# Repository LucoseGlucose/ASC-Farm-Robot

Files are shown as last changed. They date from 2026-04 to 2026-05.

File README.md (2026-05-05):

# ASC-Farm-Robot

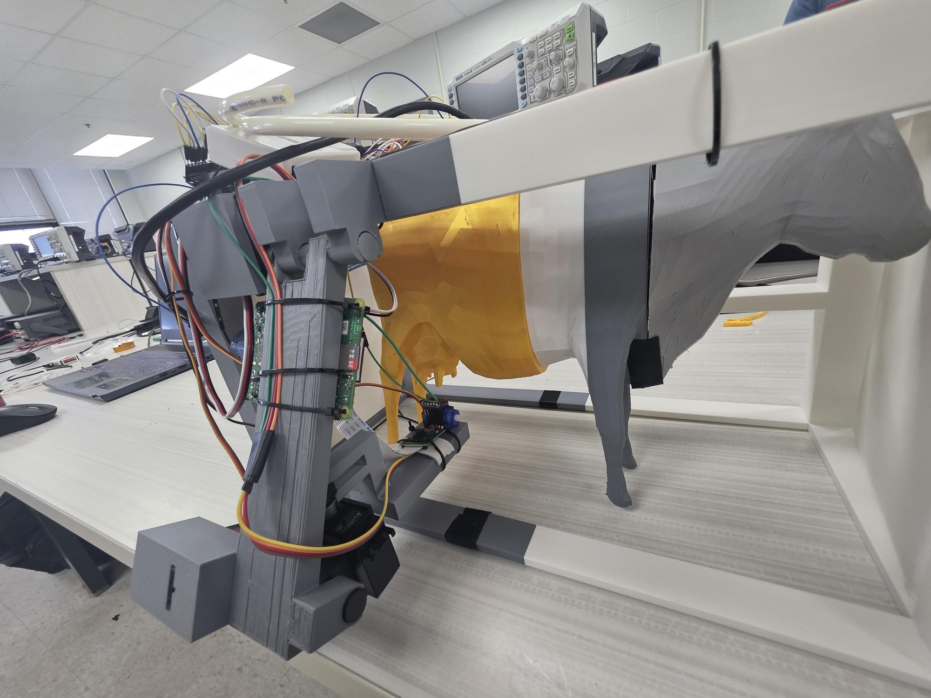
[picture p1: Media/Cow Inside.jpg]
Machine with Cow Inside


Final project for SAMET, SUNY Alfred State College of Technology course ELET 7404 Embedded and Real Time Systems. The goal was to create a scaled down prototype of a commercial DeLeval milking machine like the one at the college farm. The robot features a full 3D printed frame and arm assembly, RFID tag tracking system, powerful arm with inverse kinematics, and pump placement sensing. 

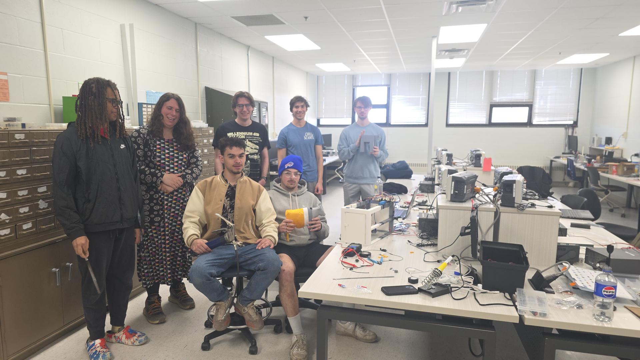
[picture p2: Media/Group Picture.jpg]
Group Picture


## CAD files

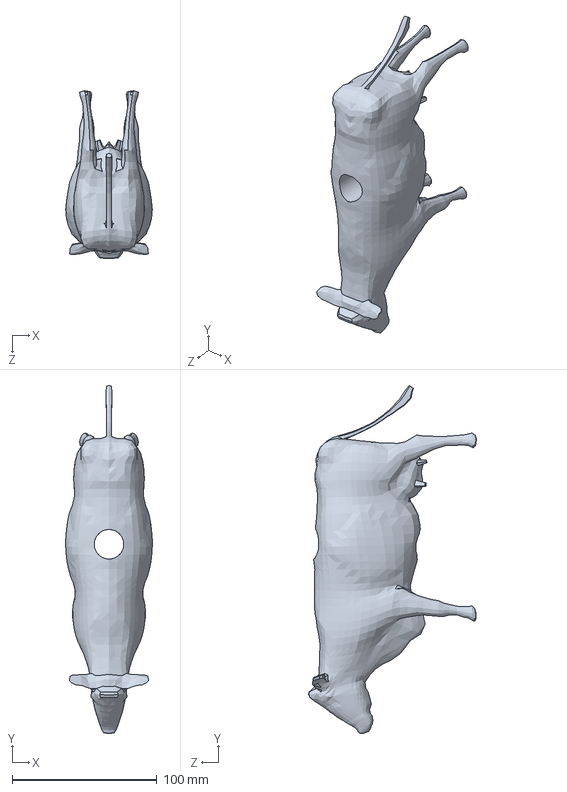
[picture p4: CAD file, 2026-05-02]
Solidworks/cowNJ.SLDPRT
59.9 x 240.3 x 115.8 mm

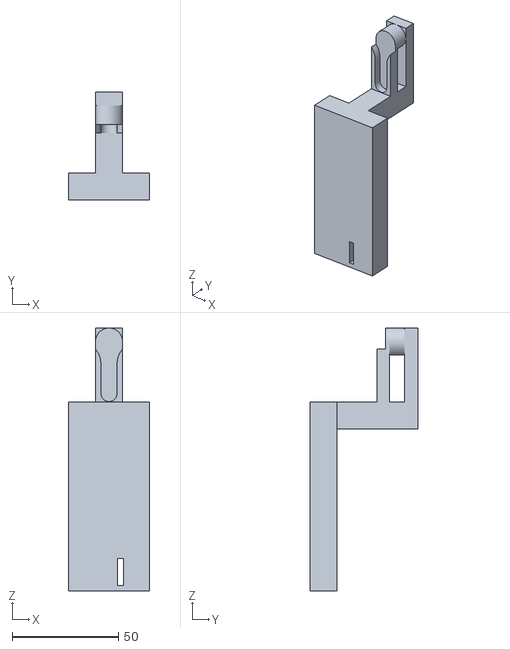
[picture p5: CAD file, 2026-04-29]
Solidworks/Exported/Lower Arm.STL
38.1 x 50.8 x 123.8

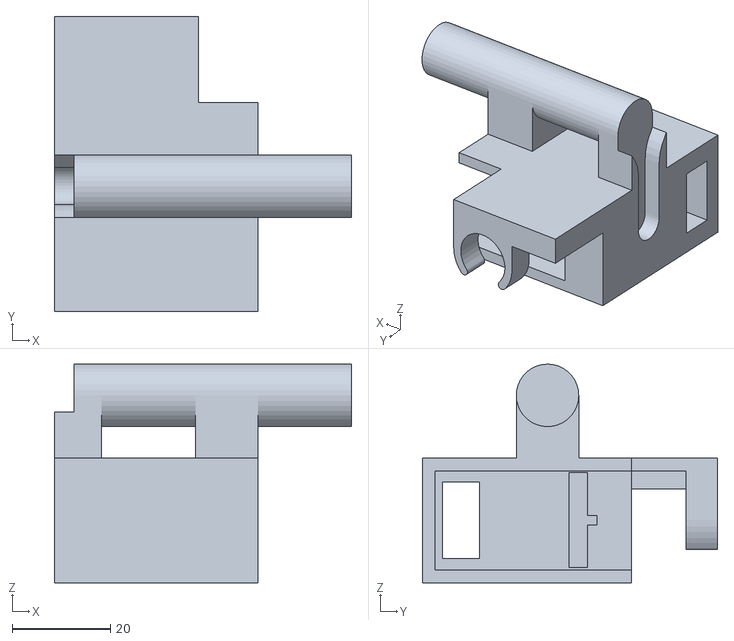
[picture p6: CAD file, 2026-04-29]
Solidworks/Exported/Arm Joint.STL
60.4 x 59.9 x 44.5

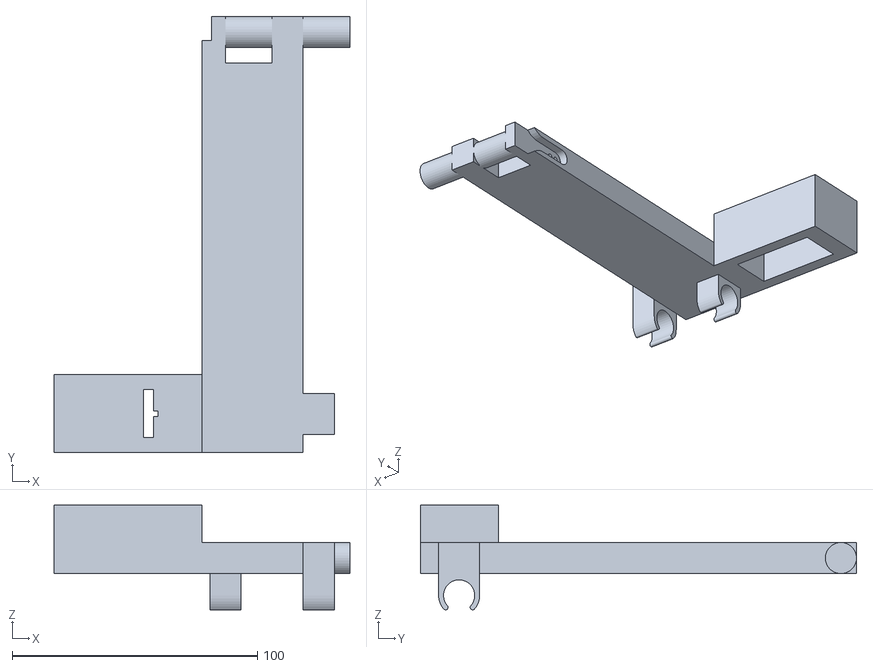
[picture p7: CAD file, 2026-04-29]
Solidworks/Exported/Upper Arm.STL
120.7 x 177.8 x 42.7

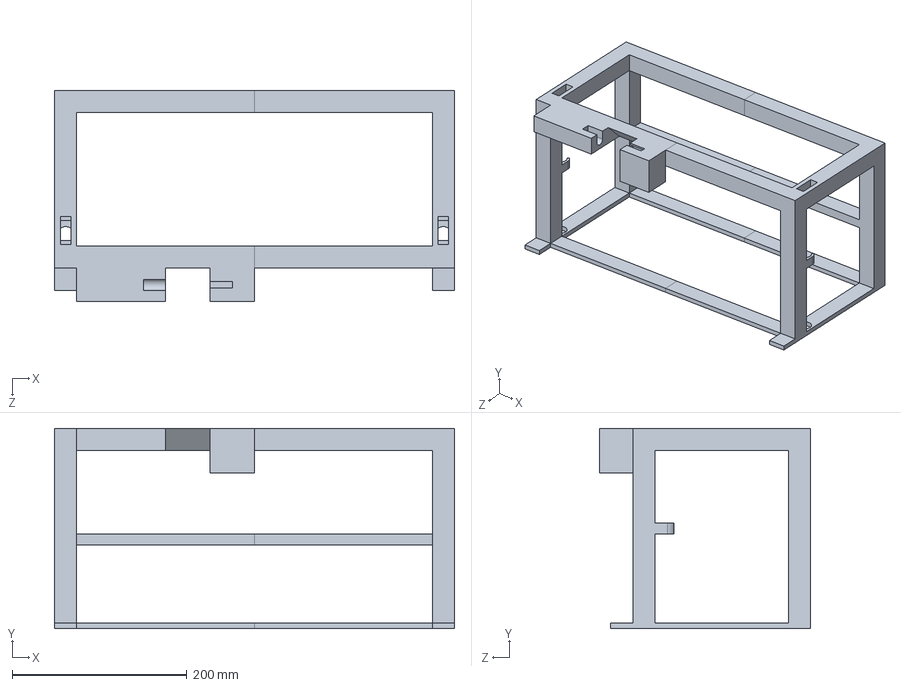
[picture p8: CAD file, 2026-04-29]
Solidworks/Frame.SLDPRT
457.2 x 228.6 x 241.3 mm

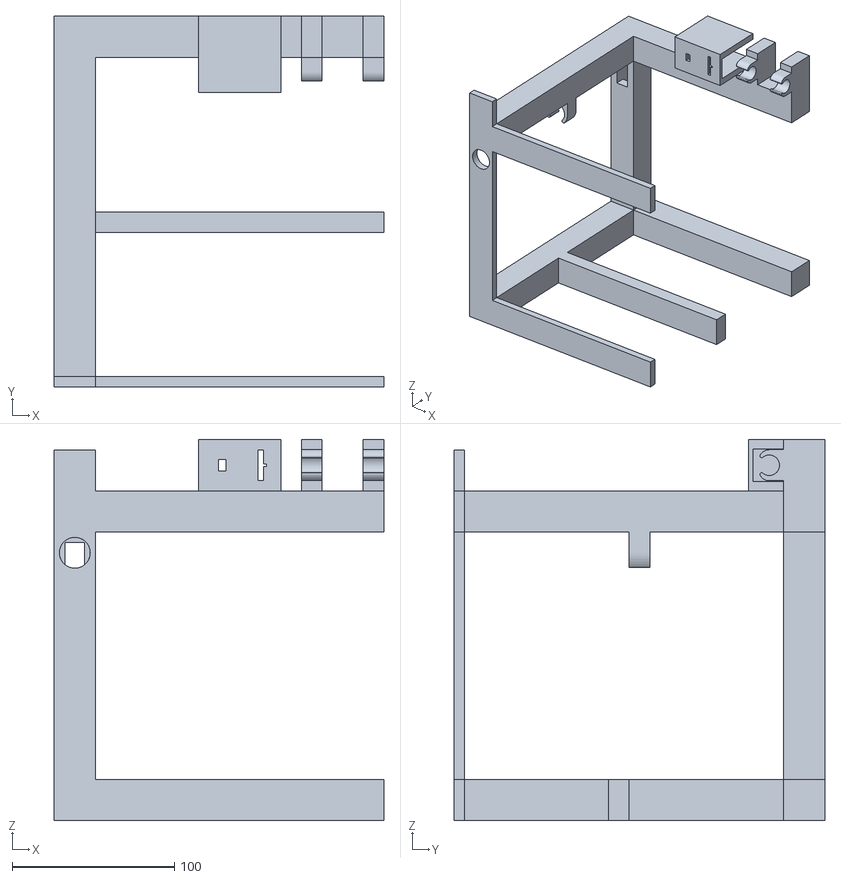
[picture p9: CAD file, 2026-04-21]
Solidworks/Exported/Left Frame.STL
203.2 x 228.6 x 234.9

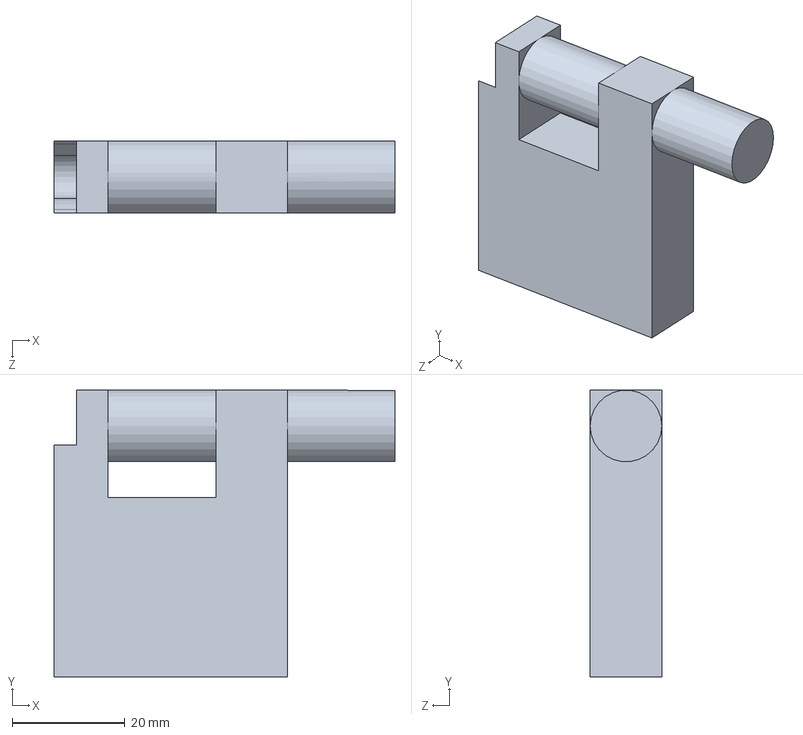
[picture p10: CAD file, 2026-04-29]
Solidworks/Upper Arm.SLDPRT
60.4 x 50.8 x 12.7 mm

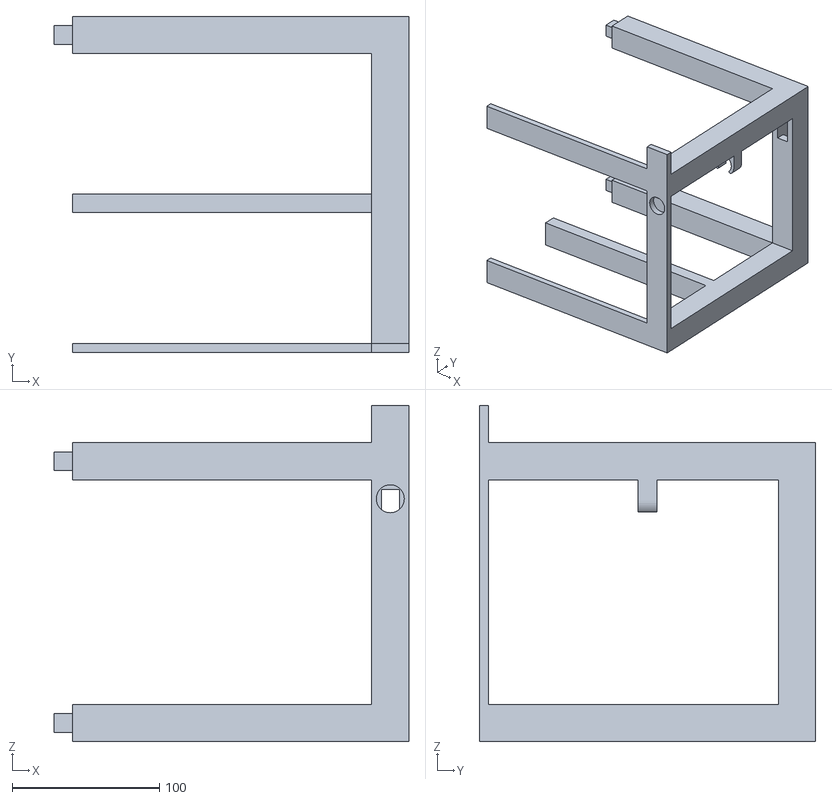
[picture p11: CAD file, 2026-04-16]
Solidworks/Exported/Right Frame.STL
241.3 x 228.6 x 228.6

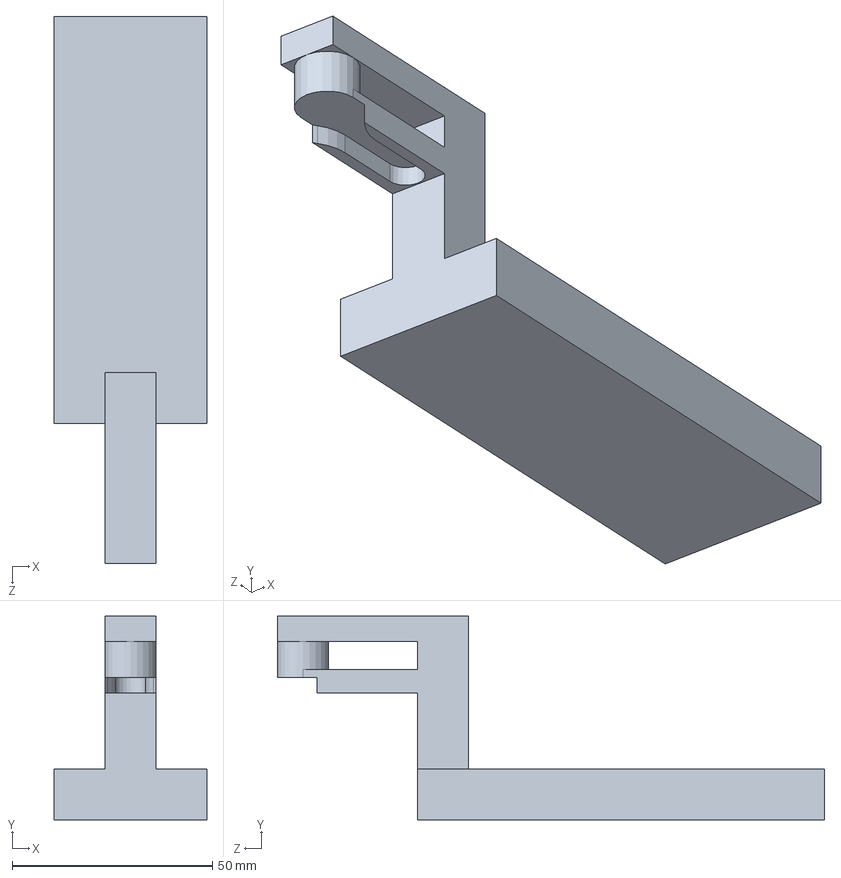
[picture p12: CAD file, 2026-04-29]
Solidworks/Lower Arm.SLDPRT
38.1 x 50.8 x 136.5 mm

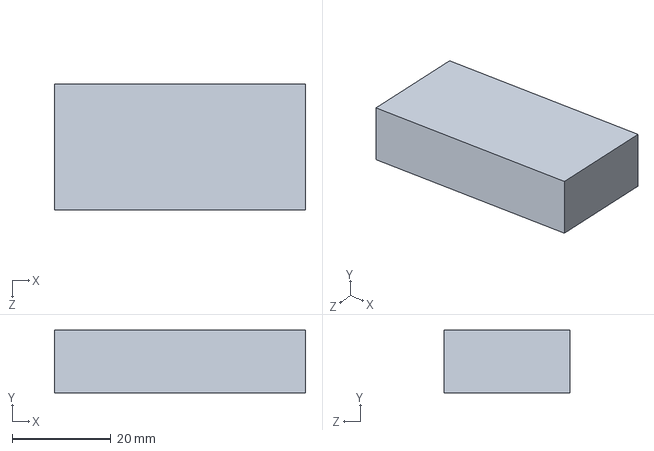
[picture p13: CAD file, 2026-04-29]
Solidworks/Arm Joint.SLDPRT
50.8 x 12.7 x 25.4 mm

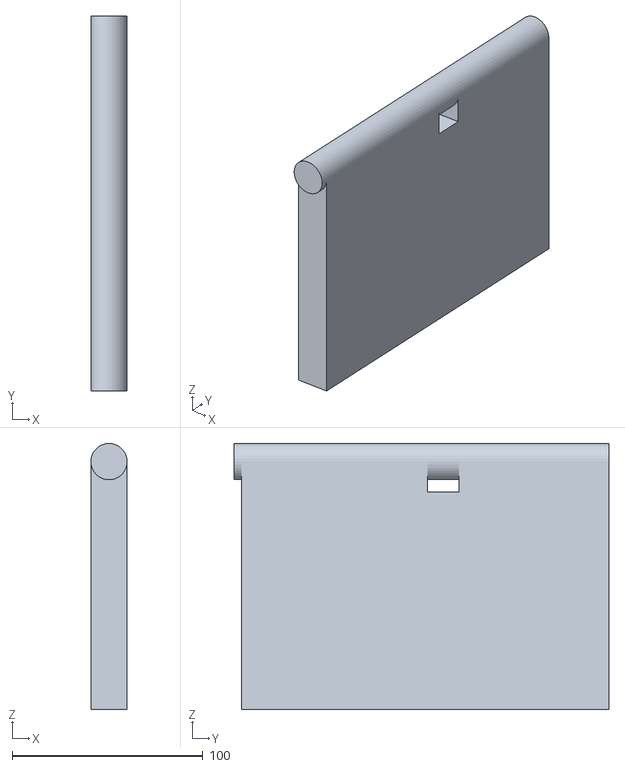
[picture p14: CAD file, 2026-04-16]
Solidworks/Exported/Gate.STL
19.1 x 196.9 x 139.7

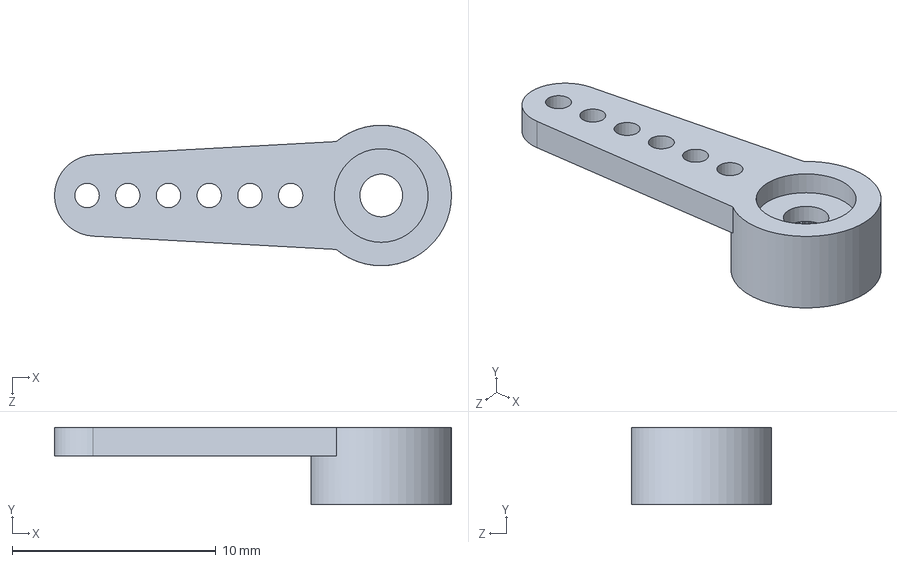
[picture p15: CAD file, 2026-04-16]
Solidworks/SG90 Arm.SLDPRT
19.5 x 3.80 x 6.90 mm

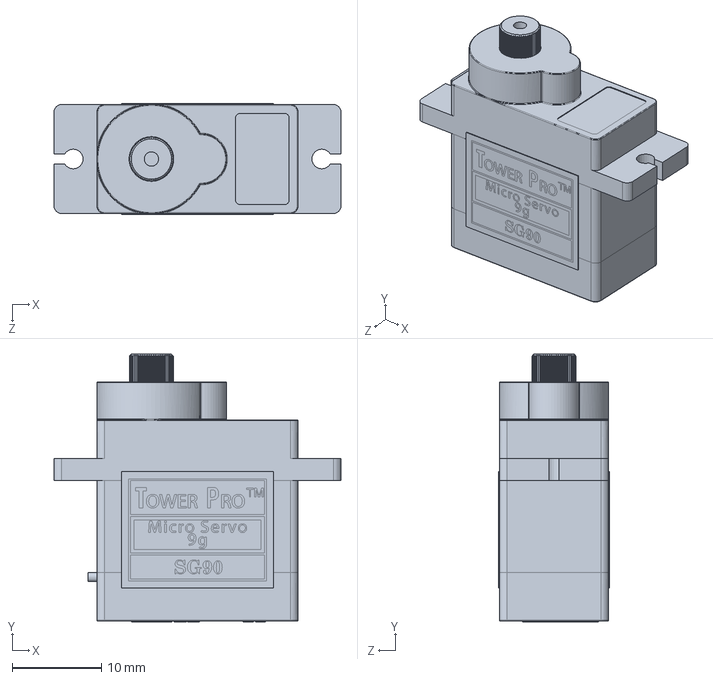
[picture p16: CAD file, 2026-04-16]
Solidworks/SG90.SLDPRT
32.1 x 30.0 x 12.4 mm

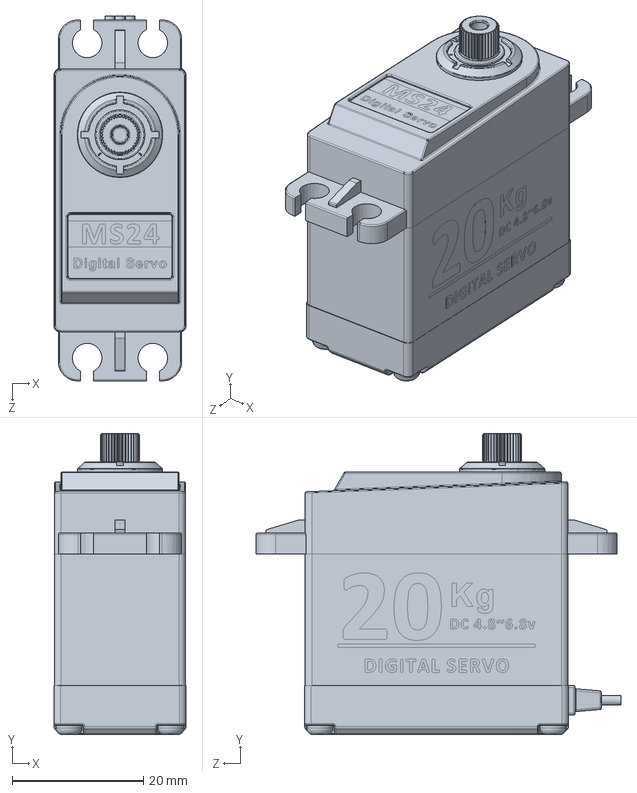
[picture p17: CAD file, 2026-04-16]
Solidworks/MS24.SLDPRT
20.1 x 45.9 x 55.6 mm

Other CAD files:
Solidworks/cow.SLDPRT
Solidworks/Gate.SLDPRT
Solidworks/MS24 Arm.SLDPRT

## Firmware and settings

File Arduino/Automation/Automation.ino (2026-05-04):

#include "RFID.h"
#include "Motors.h"
#include "Commands.h"
#include "Distance.h"
#include "Arm.h"
#include "Laser.h"
#include "Flow.h"

const int pinEStop = 22;
const int pinResetBtn = 23;

enum class SystemState
{
    STARTUP,
    IDLE,
    ENTERING,
    PREPARING,
    MILKING,
    CLEANING,
    EXITING,
    STOPPED,
};

volatile SystemState currentState = SystemState::STOPPED;

unsigned long enterStartTimeMs = 0;
unsigned long enterMaxDurationMs = 15 * 1000;

const float minYCoord = 1.f;
float uaMilkAngle;
float milkXCoord;

unsigned long milkStartTimeMs = 0;
unsigned long milkMinDurationMs = 10 * 1000;

const int pinPumpFromCow = 44;
const int pinPumpToCow = 45;

void EmergencyStop()
{
    currentState = SystemState::STOPPED;

    digitalWrite(pinPumpFromCow, LOW);
    digitalWrite(pinPumpToCow, LOW);

    MotorsDetach();
    LaserStop();
}

void setup()
{
    CommandsBegin();
    RFIDBegin();
    MotorsBegin();
    DistanceBegin();
    LaserBegin();
    FlowBegin();

    pinMode(pinEStop, INPUT_PULLUP);
    pinMode(pinResetBtn, INPUT_PULLUP);

    attachInterrupt(digitalPinToInterrupt(pinEStop), EmergencyStop, FALLING);
}

void loop()
{
    switch (currentState)
    {
        case SystemState::STOPPED:
        {
            if (digitalRead(pinResetBtn) == LOW)
            {
                currentState = SystemState::STARTUP;
                CommandSend("USTARTUP");
            }

            break;
        }
        case SystemState::STARTUP:
        {
            MotorsHome();
            MotorsAttach();
            
            currentState = SystemState::IDLE;
            CommandSend("UIDLE");
            break;
        }
        case SystemState::IDLE:
        {
            String cowID = RFIDRead();
            
            if (cowID != "")
            {
                CommandSend("R" + cowID);
                delay(250);
            }

            String command = CommandRead();

            if (command != "" && command[0] == 'U')
            {
                String message = command.substring(1);

                if (message == "ENTERING")
                {
                    CommandSend("G0O");
                    motorEntranceGate.Move(motorEntranceGate.homeAngle, motorEntranceGate.minAngle, 2.f);

                    enterStartTimeMs = millis();
                    currentState = SystemState::ENTERING;
                }
            }

            break;
        }
        case SystemState::ENTERING:
        {
            if (millis() - enterStartTimeMs  > enterMaxDurationMs)
            {
                CommandSend("G0C");
                motorEntranceGate.Move(motorEntranceGate.minAngle, motorEntranceGate.homeAngle, 3.f);
                
                currentState = SystemState::IDLE;
                CommandSend("UIDLE");
                break;
            }
            
            float iterations = 3;
            float totalDistance = 0.f;
            
            for (int i = 0; i < iterations; i++)
            {
                totalDistance += DistanceGetCm();
                delay(60);
            }

            float averageDistance = totalDistance / iterations;
            CommandSend("D" + String(averageDistance));

            if (averageDistance > 2.f && averageDistance < distanceWithCow)
            {
                CommandSend("G0C");
                motorEntranceGate.Move(motorEntranceGate.minAngle, motorEntranceGate.homeAngle, 3.f);
                
                currentState = SystemState::PREPARING;
                CommandSend("UPREPARING");
            }

            break;
        }
        case SystemState::PREPARING:
        {
            float uaGroundEndAngle = 40;
            ArmMoveHorizontal(minYCoord, motorUpperArm.homeAngle, uaGroundEndAngle, 2.f);
            delay(200);

            float aj = ArmCalcAJFromYCoord(minYCoord, uaGroundEndAngle);
            milkXCoord = ArmCalcXCoord(uaGroundEndAngle, aj);

            CommandSend(String(aj));
            CommandSend(String(milkXCoord));

            LaserStart();
            uaMilkAngle = 43;

            for (float i = uaGroundEndAngle; i < 43; i += .2f)
            {
                unsigned short distMm = LaserReadMm();
                CommandSend("D" + String(distMm));
                
                if (distMm < laserMinDistanceMm)
                {
                    unsigned short distCheckMm = LaserReadMm();
                    CommandSend("D" + String(distCheckMm));

                    if (distCheckMm < laserMinDistanceMm)
                    {
                        uaMilkAngle = i;
                        break;
                    }
                }

                ArmMoveVertical(milkXCoord, i, i + .2f, .5f);
            }

            digitalWrite(pinPumpFromCow, HIGH);
            digitalWrite(pinPumpToCow, HIGH);

            LaserStop();
            currentState = SystemState::MILKING;
            CommandSend("UMILKING");
            
            milkStartTimeMs = millis();
            break;
        }
        case SystemState::MILKING:
        {
            float flow = FlowGetRateLpS();
            CommandSend("F" + String(flow));

            if (flow < .0001f && millis() - milkStartTimeMs > milkMinDurationMs)
            {
                digitalWrite(pinPumpFromCow, LOW);
                digitalWrite(pinPumpToCow, LOW);

                currentState = SystemState::CLEANING;
                CommandSend("UCLEANING");
            }
            
            break;
        }
        case SystemState::CLEANING:
        {
            float uaUpEndAngle = 40;
            ArmMoveVertical(milkXCoord, uaMilkAngle, uaUpEndAngle, .5f);
            
            delay(200);
            ArmMoveHorizontal(minYCoord, uaUpEndAngle, motorUpperArm.homeAngle, 2.f);

            MotorsHome();
            
            currentState = SystemState::EXITING;
            CommandSend("UEXITING");

            break;
        }
        case SystemState::EXITING:
        {
            CommandSend("G1O");
            motorExitGate.Move(motorExitGate.maxAngle);

            float iterations = 5;
            float totalDistance = 0.f;

            for (int i = 0; i < iterations; i++)
            {
                totalDistance += DistanceGetCm();
                delay(60);
            }

            float averageDistance = totalDistance / iterations;
            CommandSend("D" + String(averageDistance));

            if (averageDistance > 2.f && averageDistance > distanceWithCow)
            {
                delay(2000);
                CommandSend("G1C");
                motorExitGate.Move(motorExitGate.maxAngle, motorExitGate.homeAngle, 3.f);
                
                currentState = SystemState::IDLE;
                CommandSend("UIDLE");
            }

            break;
        }
    }
}

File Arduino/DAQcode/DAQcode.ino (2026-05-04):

//Libraries and MACROES
#include <SoftwareSerial.h>

// DAQ Digital Input
int PI0 = 8;
int PI1 = 9;
int PI2 = 10;
int PI3 = 11;

//Arduino OUTPUT
int estop_out = 12;

// DAQ Digital Outputs
int estop = 4;
int home = 5;

// DAQ Analog Inputs
float wsensor = 0;
float dsensor = 0;

//variables
String str;
String str_x;
String str_y;
int n = 10;


SoftwareSerial serialFromPi = SoftwareSerial(3, 2);


void setup(){
    serialFromPi.begin(19200);
    Serial.begin(19200);

    //Initalize DAQ Digital Inputs
    pinMode(PI0, OUTPUT);
    pinMode(PI1, OUTPUT);
    pinMode(PI2, OUTPUT);
    pinMode(PI3, OUTPUT);

    //Initalize DAQ Outputs
    pinMode(estop, INPUT);
    pinMode(home, INPUT);
}

void loop(){
    if (serialFromPi.available())
    {
        Serial.print(serialFromPi.readStringUntil(';'));
        str = Serial.readString();
        if(str[0] = 'U'){
            if (str[1] == '1'){
                digitalWrite(PI0, LOW);
                digitalWrite(PI1, LOW);
                digitalWrite(PI2, LOW);
                digitalWrite(PI3, LOW);
                analogWrite(A0, 0);
            }
            if (str[1]== '2'){
                digitalWrite(PI0, HIGH);
                digitalWrite(PI1, LOW);
                digitalWrite(PI2, LOW);
                digitalWrite(PI3, LOW);
            }
            if (str[1] == '3'){
                digitalWrite(PI0, LOW);
                digitalWrite(PI1, HIGH);
                digitalWrite(PI2, LOW);
                digitalWrite(PI3, LOW);
            }
            if (str[1] == '4'){
                digitalWrite(PI0, HIGH);
                digitalWrite(PI1, HIGH);
                digitalWrite(PI2, LOW);
                digitalWrite(PI3, LOW);
            }
            if (str[1] == '5'){
                digitalWrite(PI0, LOW);
                digitalWrite(PI1, LOW);
                digitalWrite(PI2, HIGH);
                digitalWrite(PI3, LOW);
            }
            if (str[1] == '6'){
                digitalWrite(PI0, HIGH);
                digitalWrite(PI1, LOW);
                digitalWrite(PI2, HIGH);
                digitalWrite(PI3, LOW);
            }
            if (str[1] == '7'){
                digitalWrite(PI0, LOW);
                digitalWrite(PI1, HIGH);
                digitalWrite(PI2, HIGH);
                digitalWrite(PI3, LOW);
                analogWrite(A0, 0);
            }
            if (str[1] == '8'){
                digitalWrite(PI0, HIGH);
                digitalWrite(PI1, HIGH);
                digitalWrite(PI2, HIGH);
                digitalWrite(PI3, LOW);
            }
        }
        if (str[0] == 'R'){
            if (str[1] =='1'){
                analogWrite(A0, 36);
            }
            if (str[1] == 'D'){
                analogWrite(A0, 61);
            }
            if (str[1] == '3'){
                analogWrite(A0, 87);
            }
            if( str[1] == 'C'){
                analogWrite(A0, 112);
            }

            /*
            for (int l = 1; l <= 8; l++){
                
                if(str[l] == '0'){
                    analogWrite(A0, 0);
                    delay(n);
                }
                if(str[l] == '1'){
                    analogWrite(A0, 1);
                    delay(n);
                }
                if(str[l] == '2'){
                    analogWrite(A0, 2);
                    delay(n);
                }
                if(str[l] == '3'){
                    analogWrite(A0, 3);
                    delay(n);
                }
                if(str[l] == '4'){
                    analogWrite(A0, 4);
                    delay(n);
                }
                if(str[l] == '5'){
                    analogWrite(A0, 5);
                    delay(n);
                }
                if(str[l] == '6'){
                    analogWrite(A0, 6);
                    delay(n);
                }
                if(str[l] == '7'){
                    analogWrite(A0, 7);
                    delay(n);
                }
                if(str[l] == '8'){
                    analogWrite(A0, 8);
                    delay(n);
                }
                if(str[l] == '9'){
                    analogWrite(A0, 9);
                    delay(n);
                }
                if(str[l] == 'A'){
                    analogWrite(A0, 10);
                    delay(n);
                }
                if(str[l] == 'B'){
                    analogWrite(A0, 11);
                    delay(n);
                }
                if(str[l] == 'C'){
                    analogWrite(A0, 12);
                    delay(n);
                }
                if(str[l] == 'D'){
                    analogWrite(A0, 13);
                    delay(n);
                }
                if(str[l] == 'E'){
                    analogWrite(A0, 14);
                    delay(n);
                }
                if(str[l] == 'F'){
                    analogWrite(A0, 15);
                    delay(n);
                }
            }
            */
        }
        if (str[0] == 'F'){
            String F = str.substring(1);
            int flow = F.toInt();
            analogWrite(A1, flow);
        }
        if (str[0] == 'D'){
            String D = str.substring(1);
            int z = D.toInt();
            analogWrite(A2, z);
        }
        if (str[0] == 'T'){
            String T = str.substring(1);
            int time = T.toInt();
            analogWrite(A3, time);
        }
        if (str[0] == 'C'){
            for (int i = 0; i < str.length(); i++) {
                if (str.substring(i, i+1) == ",") {
                    str_x = str.substring(1, i);
                    str_y = str.substring(i+1);
                    break;
                }
            }
            int x = str_x.toInt();
            int y = str_y.toInt();
            analogWrite(A4, x);
            analogWrite(A5, y);
        }
        if (str[0] == 'G'){
            if (str[1] == 'O'){
                digitalWrite(PI0, LOW);
                digitalWrite(PI1, LOW);
                digitalWrite(PI2, LOW);
                digitalWrite(PI3, HIGH);
            }
            if (str[0] == 'C'){
                digitalWrite(PI0, HIGH);
                digitalWrite(PI1, LOW);
                digitalWrite(PI2, LOW);
                digitalWrite(PI3, HIGH);
            }
        }
        
    }
    if (Serial.available()){
        serialFromPi.print(Serial.readString());
        if (estop == HIGH){
            digitalWrite(estop_out, LOW);
        }
        if (estop == LOW){
            digitalWrite(estop_out, HIGH);
        }
        if (home == HIGH){
            Serial.println("HHOME");
        }
    }
}

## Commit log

2026-03-25 created a button
2026-04-08 Added comment to arduino file
2026-04-12 Added Solidworks files
    [Frame.SLDPRT, Upper Arm.SLDPRT]
2026-04-14 Updated Assembly file
    [Upper Arm.SLDPRT]
2026-04-15 Changed delimiter on command
    [Upper Arm.SLDPRT]
2026-04-16 organized files into folders
    [Frame.SLDPRT, Upper Arm.SLDPRT]
2026-04-16 Finished Upper Arm
    [Frame.SLDPRT, MS24 Arm.SLDPRT, MS24.SLDPRT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]
2026-04-16 Added gates and stuff
    [Frame.SLDPRT, Gate.SLDPRT, Left Frame.SLDPRT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]
2026-04-16 Exported parts to print
    [Frame.SLDPRT, Gate.STL, Left Frame.SLDPRT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]
2026-04-16 Improved gate design, checkpoint before improving arm hinge
    [Frame.SLDPRT, Gate.SLDPRT, Gate.STL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]
2026-04-21 More buttons to UI. Hide and shows corresponding buttons.
2026-04-21 Created Arduino Program to read and send Tag data to Raspberry Pi
    Wiring chart for RFID mod and Program for the Arduino to read data from tags
2026-04-21 Redesign and 3D print frame, reorganize files
    [Frame.SLDPRT, Gate.SLDPRT, Left Frame.STL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]
2026-04-24 Arduino Control Program Outline Finished
    This is the basic model for the Switch block that will allow the Pi to switch the Arduino's function. RFID has been implemented already. Motor Control and E-Stop functions still need to be finished.
2026-04-29 Finished modeling and exporting parts
    [Arm Joint.SLDPRT, Arm Joint.STL, Frame.SLDPRT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]
2026-04-29 test with servo
2026-04-30 It worked the whole time I just needed to connect their grounds
2026-05-01 Added pi stuff
    [MilkingData.csv]
2026-05-01 Create cow.SLDPRT
    Added cow file
    [cow.SLDPRT]
2026-05-02 added distance sensor test
2026-05-02 Added occupation check
    [MilkingData.csv]
2026-05-02 try to get motors moving
2026-05-02 DAQ Arduino Code added, cow mod
    [cow.SLDPRT]
2026-05-02 get motor debug info
2026-05-02 cow finalized
    [cow.SLDPRT]
2026-05-02 2024 cow
    [cow.SLDPRT, cowNJ.SLDPRT]
2026-05-02 Arduino changes
2026-05-04 Got arm to move into milking position
2026-05-04 Added reference code for flow rate, finished Arduino code
2026-05-04 made motor go in straight line precisely
2026-05-04 Added case structure for cow names
2026-05-04 git commit, things should work better now, hopefully start on camera
2026-05-04 add camera test
    [MilkingData.csv]
2026-05-05 Disabled camera
    [MilkingData.csv]
